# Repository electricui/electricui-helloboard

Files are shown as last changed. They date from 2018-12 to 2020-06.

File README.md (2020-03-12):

# Electric UI HelloBoard
This is a tiny USB based evaluation board which makes development against a common platform easier, and helps introduce new users to [Electric UI](https://electricui.com/) who may not have hardware on hand.

## Background

The board is based on the Atmel SAMD21E18 microcontroller, a neat little ARM Cortex M0 core in a compact 32 pin package.

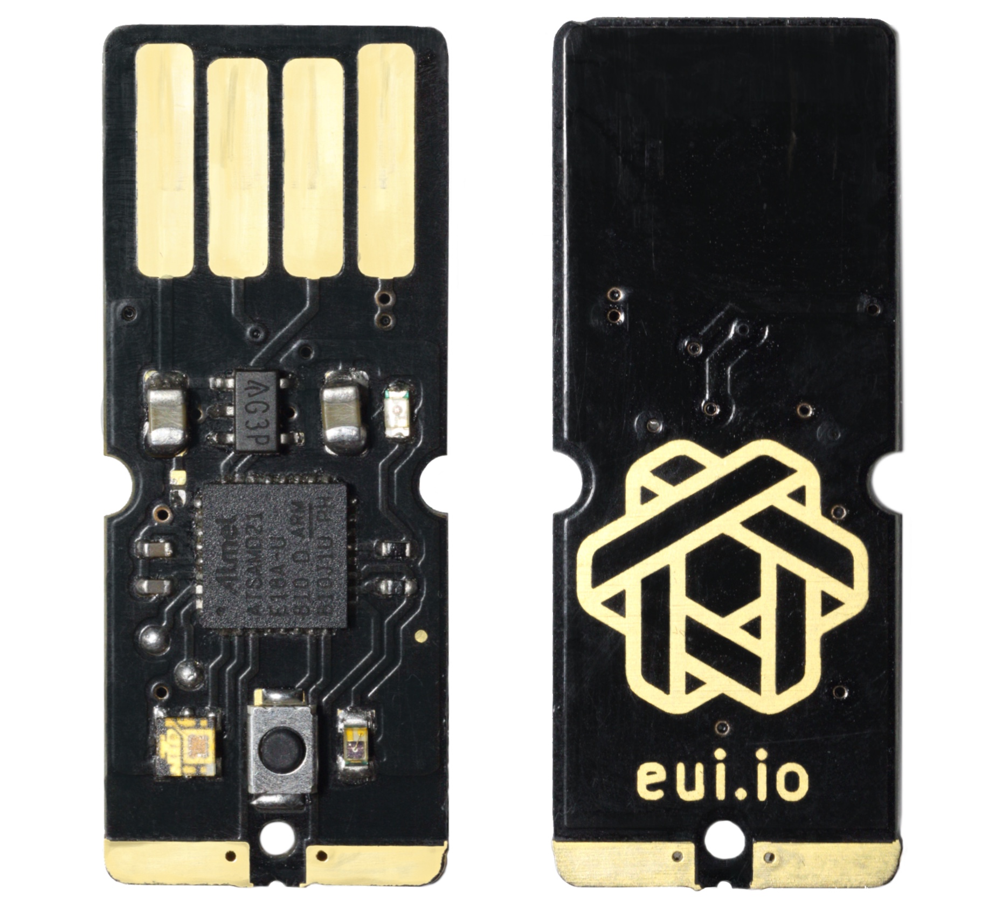
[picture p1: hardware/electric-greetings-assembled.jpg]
electric-greetings-assembled


The main goal of the board is to provide a quick and painless development experience to people who might not have played with embedded hardware before.

By including a few interactive components, and leveraging existing supported designs and software, the process should be as user-friendly as possible with no additional hardware/software modifications.

## Specifications

The board is *very* closely related to the [Adafruit Trinket M0](https://www.adafruit.com/product/3500) design, but uses an insertable male USB footprint rather than rely on a USB micro cable. The KiCAD design files, gerbers and PDF's are in `/hardware`.

It includes an ambient light sensor, click button, two capacitive touch pads, and a [APA102-2020 RGB LED](https://cpldcpu.wordpress.com/2014/08/27/apa102/) for the user to interact with, discarding the USB micro connector and some power supply related components on the Trinket.

The micro-controller is suitably capable for it's footprint:

- 256kB Flash memory (program storage)
- 32kB RAM
- 32-bit ARM M0 core running at 48MHz
- Native USB
- Supported by the Arduino IDE, or CircuitPython

The small 'thumb-drive' form factor is intended to make the sticks easy to carry and give away.

## Firmware Examples

The `/firmware` directory has a series of Arduino sketches which provide base examples for interacting with the hardware.

Most [basic and intermediate example sketches](https://github.com/electricui/electricui-embedded/tree/master/examples) in the [`electricui-embedded`](https://github.com/electricui/electricui-embedded) corpus should be directly compatible without modification.

## Flashing Firmware

The Adafruit M0 bootloader is used on this board, which supports the Arduino IDE through BOSSA, and will also enumerate as a USB mass storage device. [Simply dropping any compatible UF2 file](https://learn.adafruit.com/adafruit-feather-m0-express-designed-for-circuit-python-circuitpython/uf2-bootloader-details) on the 'drive' will update the firmware.

### Arduino IDE

The bootloader supports Arduino IDE flashing out of the box.

Install the SAMD and Adafruit SAMD hardware definitions from the *Boards Manager*, as [described in this Adafruit guide](https://learn.adafruit.com/adafruit-trinket-m0-circuitpython-arduino/using-with-arduino-ide).

Select Trinket M0 and the USB device in the Tools dropdown, then just flash the board as normal.

> **Note about Serial.print()**
>
> The Adafruit documentation is incorrect regarding usage of `Serial` vs `SerialUSB`. This hardware does not require `SerialUSB` to be used in sketches, as indicated in the [Adapting Sketches to M0](https://learn.adafruit.com/adafruit-trinket-m0-circuitpython-arduino/adapting-sketches-to-m0). That guide is relevant to other Atmel SAMD boards, but the Trinket just uses `Serial` by default.

### UF2

Plug the USB stick into a compatible computer (Windows, macOS, Linux are all fine), and drop a UF2 file into the root of the `TRINKETBOOT` disk.

### SWD Probe

A SWD programmer is required to burn the boot-loader on new hardware for the first time, but can also be used to burn firmware as part of normal development. Doing this will save some memory normally used by the boot-loader.

While any other Atmel compatible SWD programmer (OpenOCD compatible, Atmel branded, or otherwise) can be used, I used a J-Link on Linux (Solus) to flash the boards for the first time. Programming wires are either soldered on or held in place (the two exposed round pads just above the RGB led), and the JLinkExe tool is used to burn the boot-loader binary as described [in this thread](https://forums.adafruit.com/viewtopic.php?f=57&t=142170) (and below):

1. Build the bootloader by cloning the [adafruit uf2-samdx1 repo](https://github.com/adafruit/uf2-samdx1), then running `make BOARD=trinket_m0` on a *nix system.
2. Connect a compatible JLink programmer.
3. From the `/build/trinket_m0` folder, execute `JLinkExe` which I had installed in `/opt/segger/jlink`.
4. `si 1` to set the programming mode to SWD,
5. `speed 4000` to set programming speed to *4kHz*,
6. `device ATSAMD21E18` for this target,
7. `loadbin bootloader-trinket_m0-v2.0.0-adafruit.9-2-g1e0d553.bin, 0x00000000` to burn the freshly built Trinket M0 bootloader to the base address `0x00000000`.
8. `r` to reset the device,
9. `g` to run the program (though I'd advise just power cycling the target at this point),

## Manufacture & Assembly

[Makerfabs](https://www.makerfabs.com/) produced the boards, but any basic tier fab should work fine. 2.0mm thick FR4 is required to fit in normal sockets, and I'd recommend an ENIG finish as it looks a lot nicer.

The rest of the parts can be ordered from DigiKey or Adafruit (if you pull parts off existing Trinket M0 boards).

Assembly should be done with paste and hot air, or a reflow oven if possible. As this board has some fine pitch parts and 0402 components, its not the easiest board for a beginner to assemble. 

I was able to assemble boards by hand without magnification, so people familiar with 0402 and 0.5mm pitch QFN parts shouldn't have too many issues.

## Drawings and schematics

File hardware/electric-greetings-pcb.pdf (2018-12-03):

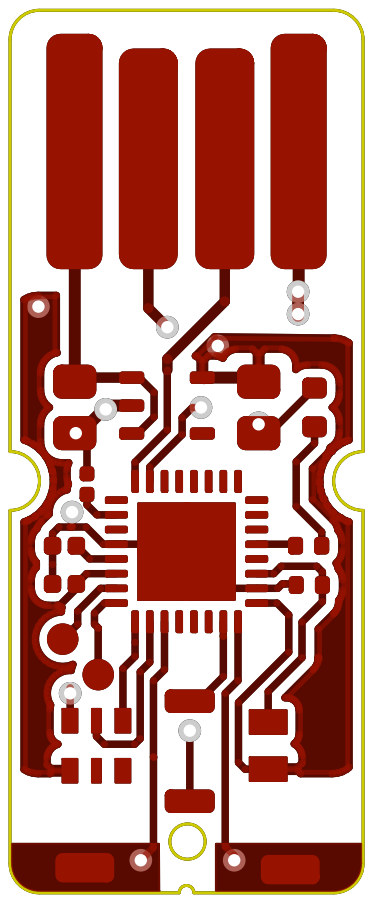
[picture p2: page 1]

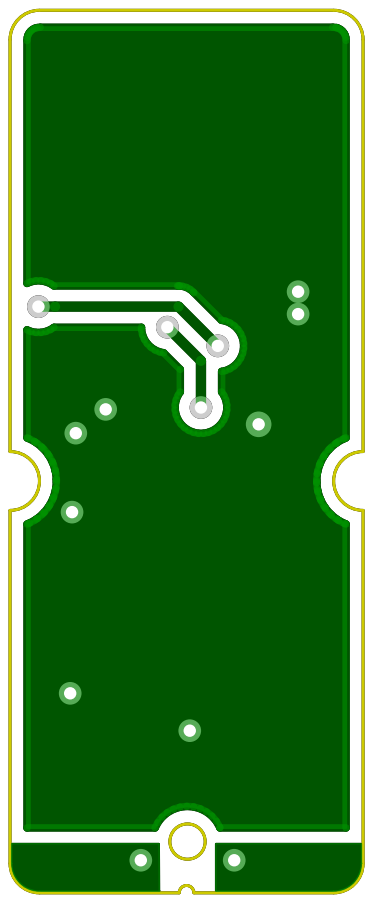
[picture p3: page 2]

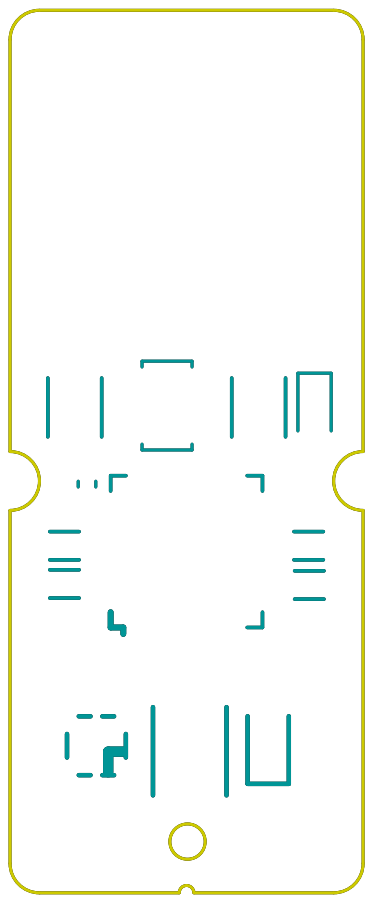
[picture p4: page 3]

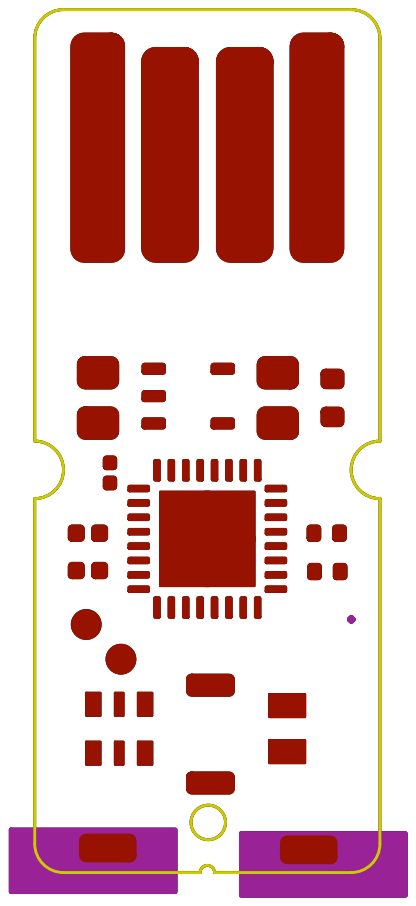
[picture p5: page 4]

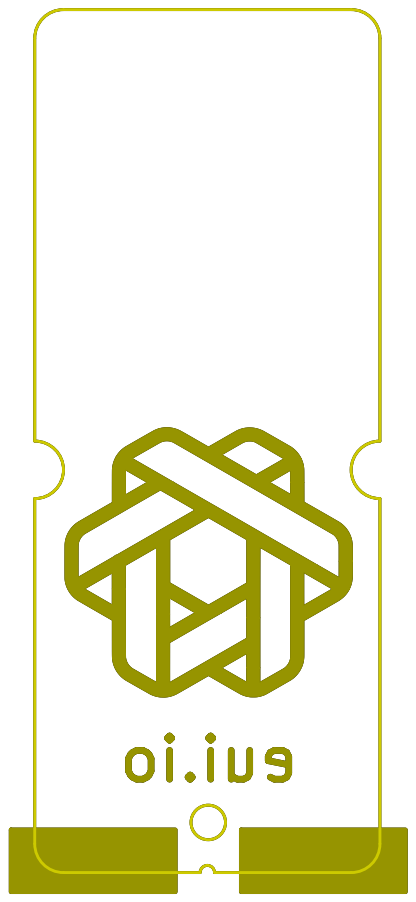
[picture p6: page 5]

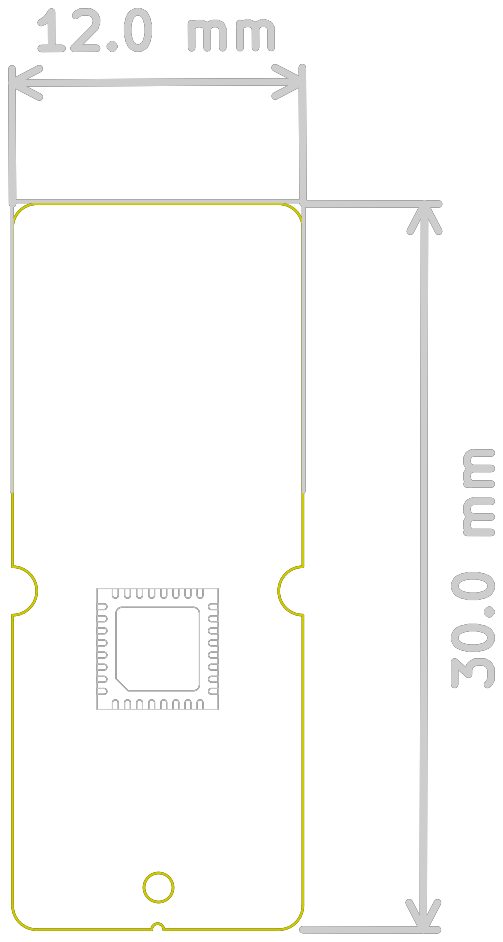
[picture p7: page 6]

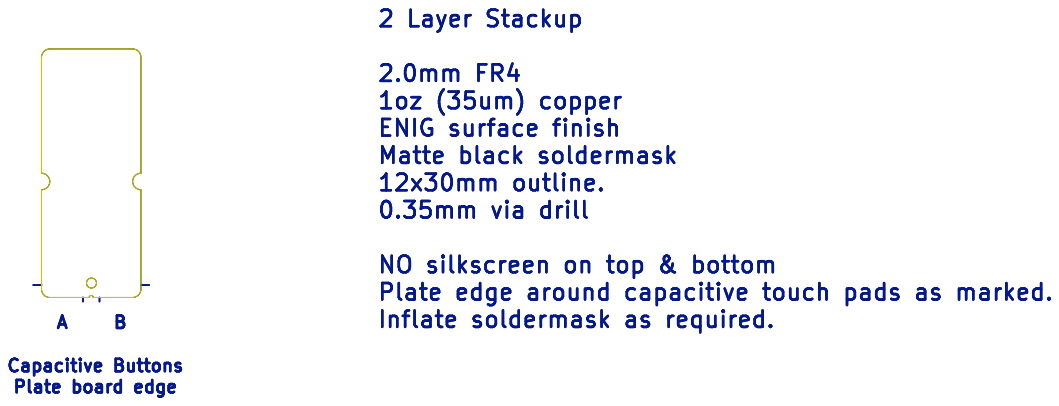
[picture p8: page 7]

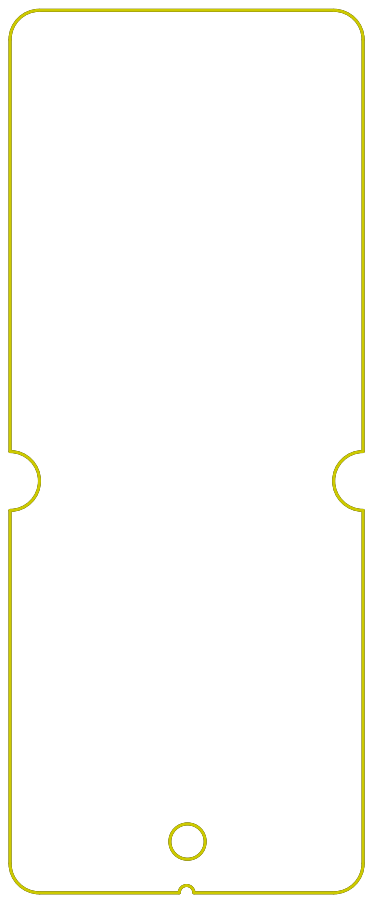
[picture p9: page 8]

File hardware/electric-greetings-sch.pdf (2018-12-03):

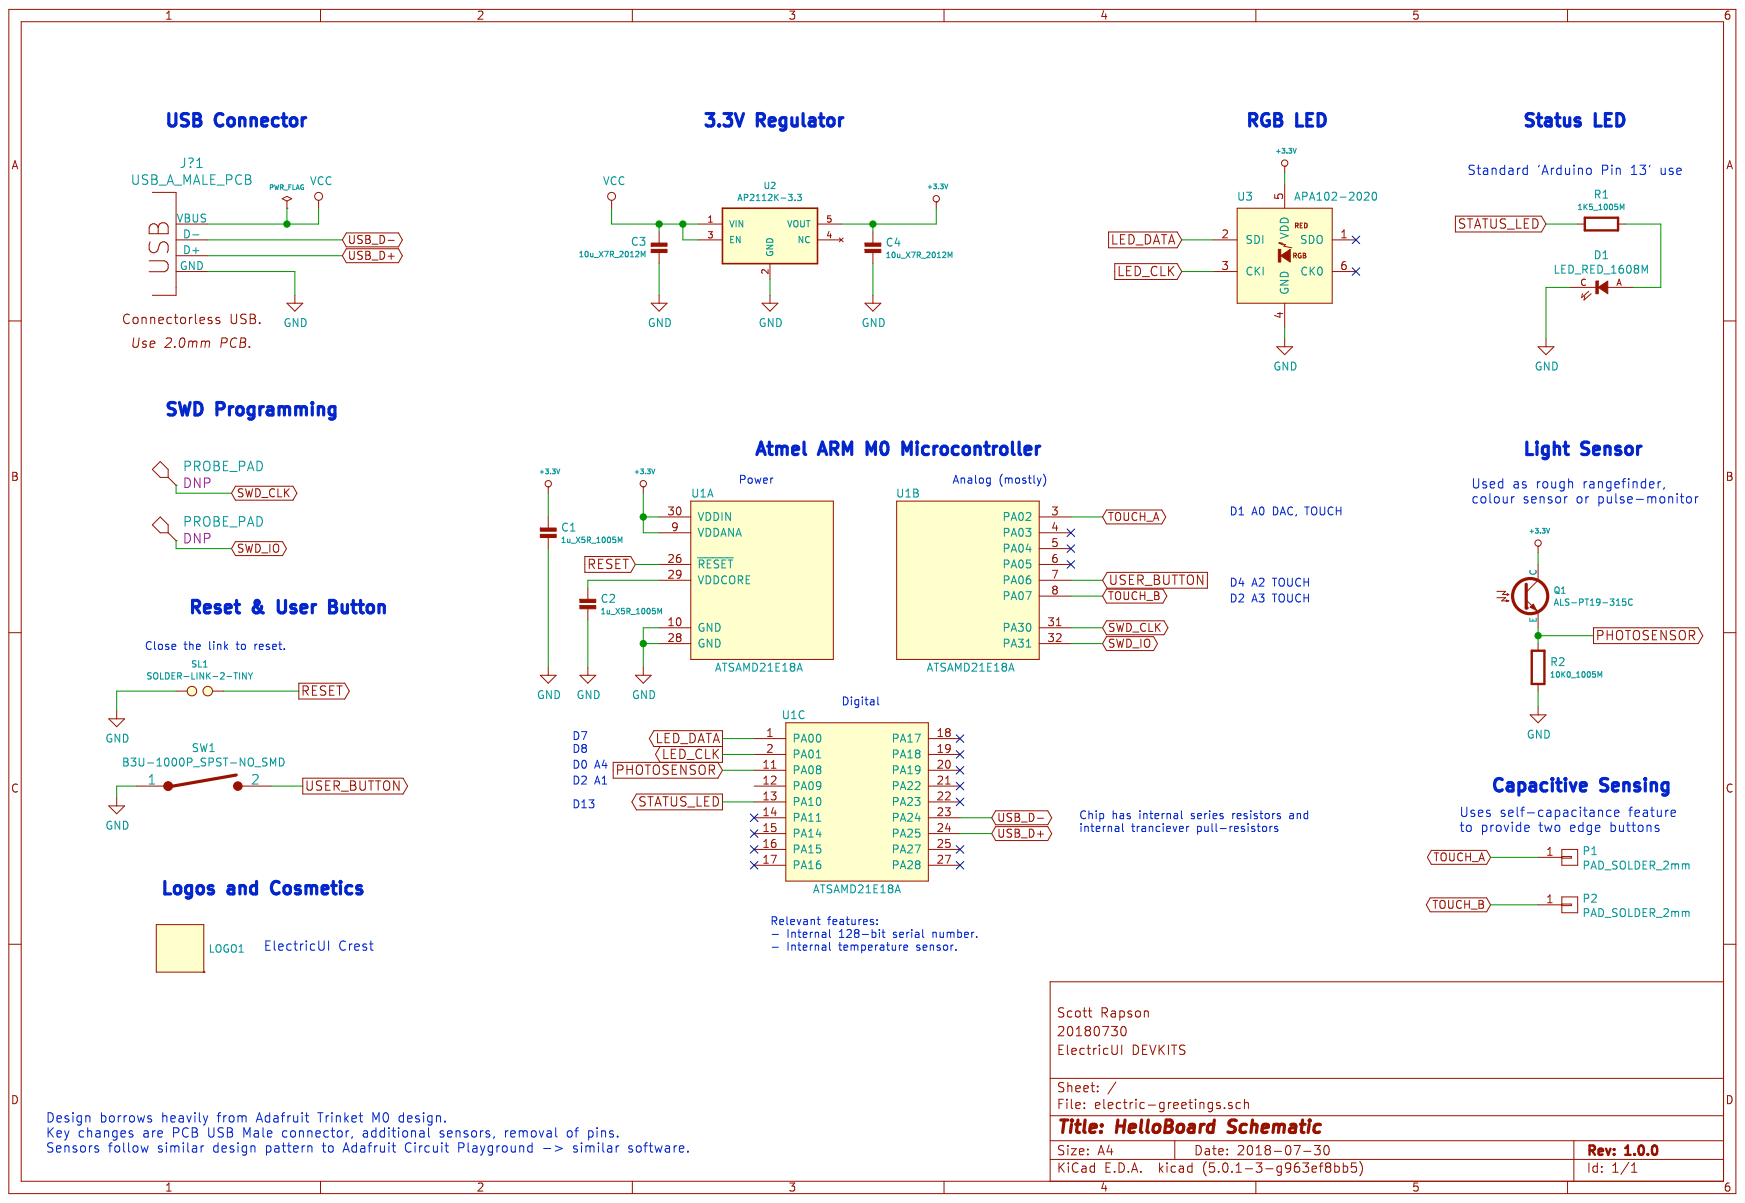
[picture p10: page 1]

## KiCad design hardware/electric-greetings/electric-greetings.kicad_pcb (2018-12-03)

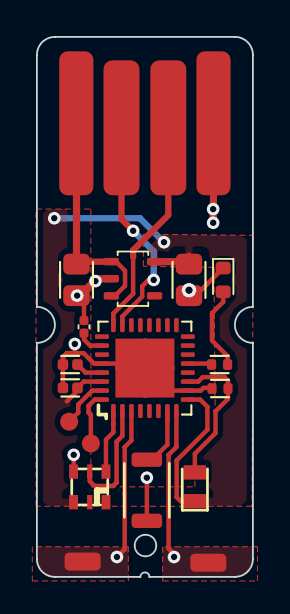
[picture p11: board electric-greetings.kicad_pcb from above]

Board: 2 copper layers, 12.0 x 30.0 mm, 19 parts (1 on the bottom side), 17 nets.

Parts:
C1, C2: 1u_X5R_1005M; CAPC1005X60N
C3, C4: 10u_X7R_2012M; CAPC2012X110N
D1: LED_RED_1608M; LEDC1608X80L40L
J?1: USB_A_MALE_PCB; USB_A_PLUG_PCB
LOGO1: LOGO; EUI_LOGO_1000X940_MASK
P1, P2: PAD_SOLDER_2mm
Q1: ALS-PT19-315C; TEMT7000X
R1: 1K5_1005M; RESC1005X40N
R2: 10K0_1005M; RESC1005X40N
SL1: SOLDER-LINK-2-TINY; SJ1005-2N
SW1: B3U-1000P_SPST-NO_SMD; B3U-1000P
TEST1, TEST2: PROBE_PAD; TP100
U1: ATSAMD21E18A; QFN33P50_500X500X100L40X24T345N
U2: AP2112K-3.3; SOT95P280X145-5L30L
U3: APA102-2020; AP102_200X200X90L

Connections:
+3.3V: C1.1, C4.1, Q1.C, U1.9, U1.30, U2.5, U3.5
GND: C1.2, C2.2, C3.1, C4.2, D1.C, J?1.4, R2.2, SL1.1, SW1.1, U1.10, U1.28, U2.2, U3.4
LED_CLK: U1.2, U3.3
LED_DATA: U1.1, U3.2
unnamed: C2.1, U1.29
unnamed: D1.A, R1.1
PHOTOSENSOR: Q1.E, R2.1, U1.11
RESET: SL1.2, U1.26
STATUS_LED: R1.2, U1.13
SWD_CLK: TEST1.1, U1.31
SWD_IO: TEST2.1, U1.32
TOUCH_A: P1.1, U1.3
TOUCH_B: P2.1, U1.8
USB_D+: J?1.3, U1.24
USB_D-: J?1.2, U1.23
USER_BUTTON: SW1.2, U1.7
VCC: C3.2, J?1.1, U2.1, U2.3

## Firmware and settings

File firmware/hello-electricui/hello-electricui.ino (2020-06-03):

#include <electricui.h>
#include <Adafruit_DotStar.h>
#include <SPI.h>

// Hardware Pin Allocations
#define PIN_BUTTON      4
#define PIN_PHOTOSENSE  2
#define PIN_STATUS      13
#define PIN_TOUCH_A     3
#define PIN_TOUCH_B     0

#define PIN_RGB_DATA    7
#define PIN_RGB_CLOCK   8
#define NUM_PIXELS      1

// RGB LED object
Adafruit_DotStar strip = Adafruit_DotStar(  NUM_PIXELS, 
                                            PIN_RGB_DATA, 
                                            PIN_RGB_CLOCK, 
                                            DOTSTAR_BGR );

typedef struct rgb_t {
  uint8_t r;
  uint8_t g;
  uint8_t b;
};

uint8_t filter_strength = 10;

// Inputs
uint16_t light_adc      = 0;
uint16_t touch_a_adc    = 0;
uint16_t touch_b_adc    = 0;
uint8_t  button_pressed = 0;

// Outputs
uint8_t status_led = 0;
rgb_t dotstar = { 0 };

char device_nickname[16] = "HelloStick Demo";

eui_interface_t usb_cdc;

eui_message_t tracked_variables[] = {
  EUI_UINT16_RO(  "light", light_adc      ),
  EUI_UINT16_RO(  "tA",    touch_a_adc    ),
  EUI_UINT16_RO(  "tB",    touch_b_adc    ),
  EUI_UINT8_RO(   "but",   button_pressed ),

  EUI_UINT8(  "r",    dotstar.r    ),
  EUI_UINT8(  "g",    dotstar.g    ),
  EUI_UINT8(  "b",    dotstar.b    ),


  EUI_UINT8( "filter", filter_strength ),
  EUI_UINT8(    "led", status_led ),
  EUI_CUSTOM(   "rgb", dotstar    ),

  EUI_CHAR_ARRAY( "name", device_nickname ),
};


void setup_pins()
{
  pinMode( PIN_BUTTON,      INPUT_PULLUP  );
  pinMode( PIN_PHOTOSENSE,  INPUT         );
  pinMode( PIN_STATUS,      OUTPUT        );
  pinMode( PIN_TOUCH_A,     INPUT         );
  pinMode( PIN_TOUCH_B,     INPUT         );

  //use the full capability of the ARM M0 ADC
  analogReadResolution(12); 
}

void setup()
{
  Serial.begin( 115200 ); //it's actually USB so baud doesn't matter
  setup_pins();
  
  usb_cdc.output_cb = &usb_write;
  eui_setup_interface( &usb_cdc );
  EUI_TRACK( tracked_variables );

  uint32_t * uuid_buf = get_chip_uuid();  //128-bit UUID
  eui_setup_identifier( (char*)uuid_buf, 16 );

  strip.begin(); 
  strip.show();  // Turn all LEDs off at start
}

void loop()
{
  while( Serial.available() > 0 )  // Process inbound serial data
  {  
    eui_parse( Serial.read(), &usb_cdc );
  }

  // Sample inputs
  touch_a_adc = analogRead( PIN_TOUCH_A );
  touch_b_adc = analogRead( PIN_TOUCH_B );
  button_pressed = !digitalRead( PIN_BUTTON );

  uint16_t raw_light = analogRead( PIN_PHOTOSENSE );
  light_adc = exponential_moving_average( light_adc, raw_light, filter_strength );

  // Control the status LED  
  digitalWrite( PIN_STATUS, status_led );

  //control the RGB led
  strip.setPixelColor( 0, dotstar.r, dotstar.g, dotstar.b );
  strip.show(); 
  
  delay(1);
}

uint16_t exponential_moving_average( uint16_t average, uint16_t input, uint8_t alpha )
{
  if(!alpha)
  {
    alpha = 1;  //0 values will cause divide by 0 errors
  }

  return (average * (alpha-1) + input) / alpha; // running average
}

uint32_t * get_chip_uuid() 
{
  static uint32_t uuid[3] = { 0 };
  uuid[0] = *(volatile uint32_t *)0x0080A00C;
  uuid[1] = *(volatile uint32_t *)0x0080A040;
  uuid[2] = *(volatile uint32_t *)0x0080A044;
  uuid[3] = *(volatile uint32_t *)0x0080A048;
  
  return uuid;
}

// Output function is called by Electric UI
void usb_write( uint8_t *data, uint16_t length )
{
  Serial.write( data, length );
}

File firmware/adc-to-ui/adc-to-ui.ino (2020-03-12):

// Configure the "rate" message to set how often data is published to the UI
// For faster performance, change comments in the loop to only send "t" and decode in UI

#include "electricui.h"

#define PUB_RATE_DEFAULT_MS 100

// Hardware Pin Allocations
#define PIN_BUTTON      4
#define PIN_PHOTOSENSE  2
#define PIN_STATUS      13
#define PIN_TOUCH_A     3
#define PIN_TOUCH_B     0

#define PIN_RGB_DATA    7
#define PIN_RGB_CLOCK   8
#define NUM_PIXELS      1

// Inputs
uint16_t light_adc      = 0;
uint16_t touch_a_adc    = 0;
uint16_t touch_b_adc    = 0;
bool     button_pressed = 0;

typedef struct {
  uint16_t a;
  uint16_t b;
} TouchValues_t;

TouchValues_t combined_touch = { 0 };

// LED Blink
uint8_t   blink_enable = 1; // if the blinker should be running
uint8_t   led_state  = 0;   // track if the LED is illuminated
uint16_t  glow_time  = 200; // in milliseconds
uint32_t  led_timer  = 0;   // track when the light turned on or off

// Configurable rate publishing to UI
uint32_t  pub_timer  = 0;   // timestamp when last message was published
uint16_t pub_duration = PUB_RATE_DEFAULT_MS;  // Amount of time between publishing data

eui_interface_t serial_comms = EUI_INTERFACE( &serial_write ); 
eui_message_t tracked_variables[] = 
{
  EUI_UINT8(  "led_blink",  blink_enable ),
  EUI_UINT8(  "led_state",  led_state ),
  EUI_UINT16( "lit_time",   glow_time ),

  EUI_UINT8_RO(  "btn",  button_pressed ),

  EUI_UINT16_RO( "tA", touch_a_adc ),
  EUI_UINT16_RO( "tB", touch_b_adc ),
  EUI_UINT16_RO( "light", light_adc ),

  EUI_CUSTOM_RO( "t", combined_touch ),
  EUI_UINT16( "rate", pub_duration ),
};

void setup() 
{
  pinMode( PIN_BUTTON,      INPUT_PULLUP  );
  pinMode( PIN_PHOTOSENSE,  INPUT         );
  pinMode( PIN_STATUS,      OUTPUT        );
  pinMode( PIN_TOUCH_A,     INPUT         );
  pinMode( PIN_TOUCH_B,     INPUT         );

  //use the full capability of the ARM M0 ADC
  analogReadResolution(12); 

  Serial.begin( 115200 );
  pinMode( LED_BUILTIN, OUTPUT );
  eui_setup_interface( &serial_comms );
  EUI_TRACK( tracked_variables );
  eui_setup_identifier( "hello", 5 );

  led_timer = millis();
  pub_timer = millis();
}

void loop() 
{
  serial_rx_handler();

  light_adc      = analogRead( PIN_PHOTOSENSE );
  touch_a_adc    = analogRead( PIN_TOUCH_A );
  touch_b_adc    = analogRead( PIN_TOUCH_B );
  button_pressed = digitalRead( PIN_BUTTON );

  if( millis() - pub_timer >= pub_duration )
  {
    eui_send_tracked("touch_a_adc");
    eui_send_tracked("touch_b_adc");
    eui_send_tracked("light");
//    eui_send_tracked("t");

    pub_timer = millis();
  }    

  // LED Blinking
  if( millis() - led_timer >= glow_time )
  {
    led_state = !led_state;
    digitalWrite( LED_BUILTIN, led_state );
    led_timer = millis();
  }   

}

void serial_rx_handler()
{
  // While we have data, we will pass those bytes to the ElectricUI parser
  while( Serial.available() > 0 )  
  {  
    eui_parse( Serial.read(), &serial_comms );  // Ingest a byte
  }
}
  
void serial_write( uint8_t *data, uint16_t len )
{
  Serial.write( data, len ); //output on the main serial port
}

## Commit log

2018-07-29 Added base project and started schematic
    Regulation, LEDs, stubs etc done.
    [electric-greetings.sch]
2018-07-30 Added atmel microcontroller, notes, layout changes
    [electric-greetings.sch]
2018-07-30 Fleshing out schematic. Started PCB shape, placement and cosmetics.
    [electric-greetings.kicad_pcb, electric-greetings.sch]
2018-11-10 Schematic tweaks, placement changes, routing
    Most routing done, added capacitive buttons, remapped micro pins slightly.
    [electric-greetings.kicad_pcb, electric-greetings.sch]
2018-11-10 More minor tweaks, finished all routing
    Most cosmetics finished, just iterating on useless details now
    [electric-greetings.kicad_pcb, electric-greetings.sch]
2018-11-10 Removed usb logo
    [electric-greetings.kicad_pcb, electric-greetings.sch]
2018-11-11 Fixed SWD programming points with 1mm pad footprint
    [electric-greetings.kicad_pcb, electric-greetings.sch]
2018-12-03 Manufacturing files generated
    Exported gerbers, generated PDF's.
    [electric-greetings-B.Cu.gbl, electric-greetings-B.Mask.gbs, electric-greetings-B.Paste.gbp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]
2019-01-28 Cleaned up HW file tree
    [electric-greetings-B.Cu.gbl, electric-greetings-B.Mask.gbs, electric-greetings-B.Paste.gbp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]
2019-01-29 Adds arduino hardware bringup sketch
    Validates hardware functions as intended.
2019-04-21 Adds user adjustable filter to photosensor values
    Also exposes LED parameters as separate tracked variables.
2020-03-12 Readme update, file structure rework
    Also added an image of the hardware!
    [electric-greetings-B.Cu.gbl, electric-greetings-B.Mask.gbs, electric-greetings-B.Paste.gbp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]
